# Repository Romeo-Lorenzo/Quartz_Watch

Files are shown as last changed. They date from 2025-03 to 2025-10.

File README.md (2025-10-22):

# DIY Quartz Watch project

## Introduction
This is my take at making my own quartz watch with a twist.
Driven by a PCF2003 chip from NXP as well as an STM32WB for bluetooth capability and controlling the subdial driving system in order to display data from the equipped sensors:
- Barometer
- Compass
- VBat
- Temp
- 1 cell lithium charge and discharge
- Very low power circuitry, 150nA continuous current consumption and 150mA with STM32 turned on. Designed to be equipped of two Airpods1 batteries in parralel for 50mAh total.

##Hardware:

  The hardware is divided into electrical and mecanical hardware

  ###Electrical:
  - 6 layer 36mm PCB board designed to replace original PCB from a Miyota 2035 movement. The PCB has two contact pads for two Miyota 2035 movements to drive both main and sub-dial. It is equipped with contact pads to ease programming of both the STM32 and the PCF 2003, most likely with pogo pin alignement 3D print to come.

PCB dial side
PCB caseback side
PCB
  
  - TODO Monolayer PCB to mount as shield on Nucleo board equipped with OP Amp to be able to output the voltage necessary to program the PCF 2003. Will most likely be designed as a programming station and include the pogo pins and debug connector for programming the STM32 as well and be integrated with the forementioned 3d model to print.
 
  ###Mecanical:
  - Onshape designed 36mm watch case with high water resistance in mind, a water tight push button to control subdial and STM32 ON time.
Watch assembly dial view
Watch assembly caseback view

Note that the Miyota 2035 movements will have to be modified, taking it apart and filing away the excess material on the bottom holding plate for the subdial movement is an easy fit and a tutorial on how to take apart and prepare the movements will be released.
The case is not yet finished but I estimate a 5 atm water tight watch, tolerances for CNC machinig will have to be tested. Crown will be a screw-in watertight type, a silicon membrane will ensure watertightness of the push button all the while allowing the inside barometer to read pressure, especially fun underwater.

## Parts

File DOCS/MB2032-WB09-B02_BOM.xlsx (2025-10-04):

 |  |  | Bill of materials
 |  |  | Board reference: | MB2032
 |  |  | Variant: | WB09
 |  |  | PCB revision: | B
 |  |  | Assembly revision: | 02
 |  |  | Date: | 6/21/2024
Designator | Description | Package | Manufacturer | Manufacturer_Part_Number | Fitted | Quantity
C2 | Capacitor, MLCC, 0.9pF, 50V, COG, +/-0.05pF, 0402, T=0.5mm | 0402 | MURATA | GJM1555C1HR90WB01 | Fitted | 1
C3, C6, C11, C12 | Capacitor, MLCC, 100nF, ±10%, X7R, 25V, 0402, T=0.5mm | 0402 | MURATA | GRM155R71E104KE14D | Fitted | 4
C4, C5 | Capacitor, C0G, 3 pF, 50V, NPO, ±0.1pF, 0402, T=0.5mm | 0402 | WALSIN TECHNOLOGY CORPORATION | 0402N3R0B500CT | Fitted | 2
C7 | Capacitor, MLCC, 20pF, 25V, COG, +/-2%, 0201, T=0.33mm | 0201 | MURATA | GJM0335C1E200GB01 | Fitted | 1
C8, C9 | Capacitor, MLCC, 10pF, 50V, NPO, +/-5%, 0402, T=0.5mm | 0402 | YAGEO | CC0402JRNPO9BN100 | Fitted | 2
C13 | Capacitor, MLCC, 1uF, X7R, 6.3V, 0402, ± 10%, T=0.5mm | 0402 | MURATA | GRM155R70J105KA12 | Fitted | 1
C14, C15 | Capacitor, MLCC, 4.7uF, X5R, 10 V, 0402, ± 20%, T=0.5mm | 0402 | MURATA | GRM155R61A475MEAAD | Fitted | 2
C16 | Capacitor, MLCC, 0.22uF, X5R, 6.3V, +/-10%, 0402, T=0.5mm | 0402 | YAGEO | CC0402KRX5R5BB224 | Fitted | 1
CN1, CN2 | Header, 25x2, 12.7mm, VR, SMD, T=4.83mm |  | SAMTEC | FTSH-125-02-L-DV | Fitted | 2
HW1 | RFI shield can, 20x15x3mm | 20x15x3mm | HARWIN | S02-20150300 | Fitted | 1
JP1 | Header, 3x1, 2.54mm, VR, TH, T=5.84mm/2.54mm |  | SAMTEC | TSW-103-07-F-S | Fitted | 1
L2 | Inductor, MLCC, 22nH, ±2%, 350mA, 0.58R, 0402, T=1.45mm | 0402 | MURATA | LQG15HN22NG02D | Fitted | 1
L3 | Inductor, MLCC, 10uH, ±20%, 300mA, 845mR, 0805, T=1.45mm | 0805 | MURATA | LQM21DN100M70L | Fitted | 1
R1, R10 | Resistor, 0R, 0402, +/-5%, 1/16W | 0402 | YAGEO | RC0402JR-070RL | Fitted | 2
R3 | Resistor, 100K, 0402, +/-1%, 1/16W | 0402 | YAGEO | RC0402FR-07100KL | Fitted | 1
SB6, SB7, SB9, SB11, SB14, SB16, SB17, SB20, SB28, SB32, SB34, SB37, SB38, SB41, SB43, SB47, SB48, SB55, SB57 | Solder Bridge 0402 ON | 0402 | YAGEO | RC0402JR-070RL | Fitted | 19
SC1, SC2, SC7, SC8 | shield clip Harwin S0981-46R to fix RF shielded cavity - SMT RFI Shield Clip, Corner (T+R) | 0.8x4.7x1.4mm | HARWIN | S0981-46R | Fitted | 4
SC3, SC4, SC5, SC6 | shield clip Harwin S0951-46R to fix RF shielded cavity | 1.1x3.9mm | HARWIN | S0951-46R | Fitted | 4
U1 | Bluetooth® Low Energy wireless SoC | QFN32 | STMICROELECTRONICS | STM32WB09KEV6TR | Fitted | 1
U2 | 2.4 GHz low pass filter matched to BLUENRG-LP-LPS | CSP6 | STMICROELECTRONICS | MLPF-NRG-01D3 | Fitted | 1
X1 | Crystal, 32MHz, 8pF, +/-10ppm, 60R, 2x1.6mm | 2x1.6mm | NDK | NX2016SA-32MHZ-EXS00A-CS06654 | Fitted | 1
X2 | Crystal, 32.768kHz, 7pF, +/-20ppm, 80K, 2.05x1.2mm | 2.05x1.2mm | NDK | NX2012SA-32.768KHZ-EXS00A-MU00389 | Fitted | 1
C1 | Capacitor, MLCC, 6.8pF, 50V, C0G, +/-0.05pF, 0402, T=0.5mm | 0402 | MURATA | GJM1555C1H6R8WB01 | Not Fitted | 0
C10 | Capacitor, MLCC, 100nF, ±10%, X7R, 25V, 0402, T=0.5mm | 0402 | MURATA | GRM155R71E104KE14D | Not Fitted | 0
CN3 | Header, 7x2, 1.27mm, VR, T=5.97mm, FTSH series STDC14 without Alignment Pin |  | SAMTEC | FTSH-107-01-L-DV-K | Not Fitted | 0
CN4 | Connector_RF, 0Hz to 6GHz, 50R, VR, SMD, T= 1.25mm |  | HIROSE | U.FL-R-SMT-1 | Not Fitted | 0
R2 | Resistor, 0R, 0402, +/-5%, 1/16W | 0402 | YAGEO | RC0402JR-070RL | Not Fitted | 0
R4, R5, R6, R7, R8 | Resistor, 47R, 0402, +/-1%, 1/16W | 0402 | YAGEO | RC0402FR-0747RL | Not Fitted | 0
R9 | Resistor, 100R, 0402, +/- 1%, 1/16W | 0402 | YAGEO | RC0402FR-07100RL | Not Fitted | 0
SB1, SB2, SB3, SB4, SB5, SB8, SB10, SB12, SB13, SB15, SB18, SB19, SB21, SB22, SB23, SB24, SB25, SB29, SB30, SB31, SB33, SB35, SB36, SB39, SB40, SB42, SB44, SB45, SB46, SB49, SB51, SB52, SB53, SB54, SB56 | Solder Bridge 0402 ON | 0402 | YAGEO | RC0402JR-070RL | Not Fitted | 0

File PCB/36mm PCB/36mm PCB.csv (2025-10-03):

Id | Référence | Empreinte | Quantité | Désignation | Fournisseur et réf
1 | R20,R16,R14,R15,R10,R13,R19 | R_0201_0603Metric | 7 | 100k
2 | R4,R5,R6,R12,R11,R8,R7 | R_0201_0603Metric | 7 | 2k
3 | D2 | D_0201_0603Metric | 1 | D
4 | L1 | L_0201_0603Metric | 1 | 27n
5 | R2,R1,R9 | R_0201_0603Metric | 3 | 0
6 | IC2 | BGA9C40P3X3_128X128X54 | 1 | BMM350
7 | CLPT1,C6,C7,CSPT1,C3,C2 | C_0201_0603Metric | 6 | 1u
8 | Y1 | LFXTAL062558Reel | 1 | LFXTAL062558Reel
9 | R17 | R_0201_0603Metric | 1 | 1k
10 | C4,C13,C1,C9,C17,C11,C10,C5,C16 | C_0201_0603Metric | 9 | 100n
11 | C15,C14 | C_0201_0603Metric | 2 | 4.7u
12 | C12 | C_0201_0603Metric | 1 | 220n
13 | IC3 | BGA25C40P5X5_213X207X58 | 1 | STM32L011E4Y6TR
14 | Q6,Q4,Q3,Q7,Q5 | 2N7002KQBZ | 5 | 2N7002KQBZ
15 | IC4 | TPS22991BRAAR | 1 | TPS22991BRAAR
16 | IC10,IC8,IC7,IC9 | BGA4C35P2X2_73X73X50 | 4 | MAX40200ANS+T
17 | TPS3424-1 | SOT-583-8 | 1 | ~
18 | TP15 | TestPoint_Pad_D1.0mm | 1 | B-
19 | C8 | C_0201_0603Metric | 1 | 200n
20 | IC1 | PCF2003DUS | 1 | PCF2003DUS
21 | R18 | R_0201_0603Metric | 1 | 47k
22 | U1 | BMP581 | 1 | BMP581
23 | IC6 | Hall effect | 1 | AS5510-DWLM
24 | TP14 | TestPoint_Pad_D1.0mm | 1 | B+
25 | IC5 | SON50P300X200X100-9N-D | 1 | MCP73831-2ACI_MC
26 | J3 | Battery pogo pins | 1 | Conn_01x02
27 | LDLN025PU1 | OnSemi_XDFN4-1EP_1.0x1.0mm_EP0.52x0.52mm | 1 | ~
28 | TP18 | Pogo pin 1x1 | 1 | SWCLK
29 | L3,L2 | Miyota 2035 | 2 | L
30 | TP21 | Pogo pin 1x1 | 1 | VSS
31 | SW5 | Wurth side button 434331013822 | 1 | SW_MEC_5E
32 | TP20 | Pogo pin 1x1 | 1 | VDD
33 | TP19 | Pogo pin 1x1 | 1 | NRST
34 | TP16 | Pogo pin 1x1 | 1 | VDD Prog
35 | TP17 | Pogo pin 1x1 | 1 | SWDIO

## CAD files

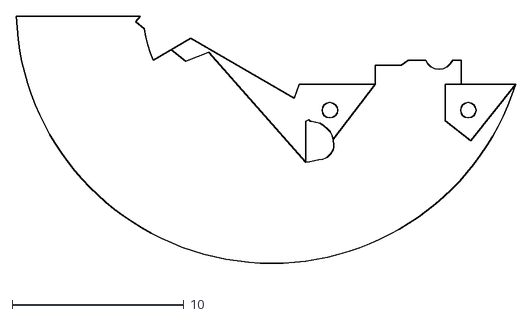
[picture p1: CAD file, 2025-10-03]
PCB/36mm PCB/36mm PCB outline.dxf
29.1 x 15.2

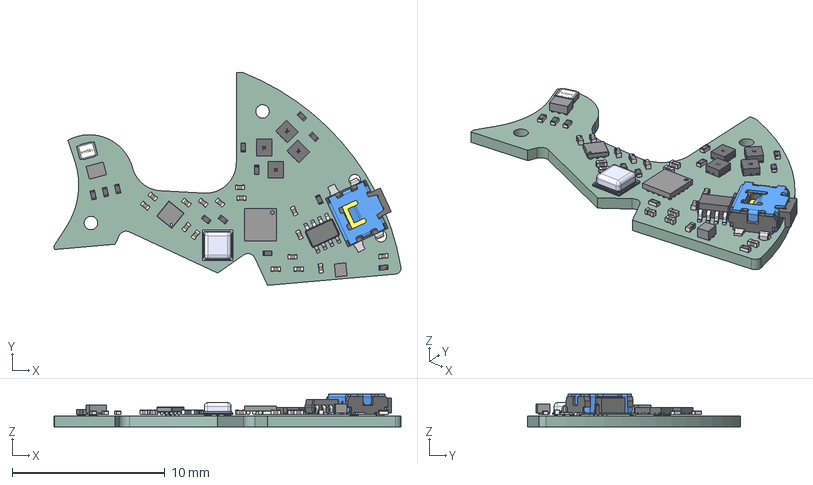
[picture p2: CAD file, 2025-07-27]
PCB/Watch_PCB/Watch_PCB.step
22.7 x 13.9 x 2.14 mm
C_0201_0603Metric x 15
ABS04W-32.768KHZ-4-D2-T5
R_0201_0603Metric x 12
Pins x 2
SOT8015 LF x 4
SOT8015 Body x 4
L_0201_0603Metric
Frame
washer
Contact plate
Stem
Cover
BMP581
BMM350
SC-70-8
Watch_PCB_PCB

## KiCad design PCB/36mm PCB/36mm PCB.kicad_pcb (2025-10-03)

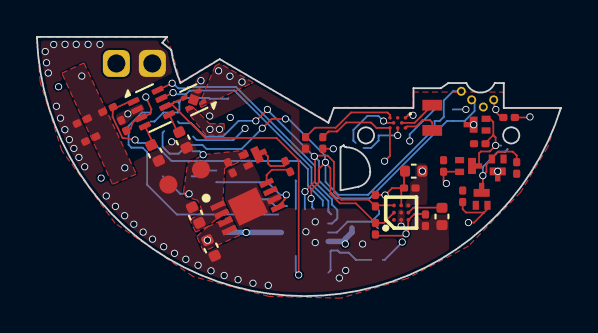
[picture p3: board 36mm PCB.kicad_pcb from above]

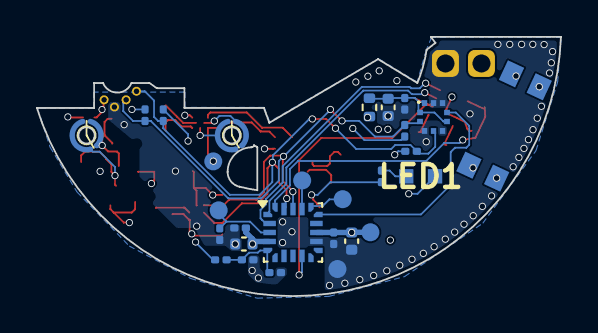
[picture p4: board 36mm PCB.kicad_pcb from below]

Board: 6 copper layers, 29.1 x 14.4 mm, 65 parts (28 on the bottom side), 34 nets.

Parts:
C9, C10, C11, C17, C21, C24, C27, C28, C29: 100n; C_0201_0603Metric
C15, C22: 4.7u; C_0402_1005Metric
C18: 2.2u; C_0402_1005Metric
C20: 220n; C_0201_0603Metric
C23, C25, C26, C30: 1u; C_0402_1005Metric
CLPT1: 11.8n; C_0402_1005Metric
CSPT1: 4.7n; C_0402_1005Metric
IC1: PCF2003DUS
IC2: BMM350; BGA9C40P3X3_128X128X54
IC5: MCP73831-2ACI_MC; SON50P300X200X100-9N-D
J1: Conn_01x04_Pin; Hall effect
J2: Conn_01x02_Socket; Battery 36mm watch
J3: Conn_01x02; Battery pogo pins
L2, L3: L; Miyota 2035
LDLN025PU1: OnSemi_XDFN4-1EP_1.0x1.0mm_EP0.52x0.52mm
LED1: 150060WS75000
Q3, Q4, Q5, Q6, Q7: 2N7002KQBZ
R1, R2: 0; R_0201_0603Metric
R3, R4, R5, R9, R22, R23: 4.7k; R_0201_0603Metric
R6: 500; R_0201_0603Metric
R7, R8, R13, R14, R18, R19, R20: 100k; R_0201_0603Metric
R11: 10; R_0402_1005Metric
R15: 47k; R_0201_0603Metric
R16: 1k; R_0201_0603Metric
R17: 2k; R_0201_0603Metric
SW5: SW_MEC_5E; Wurth side button 434331013822
TP16: VDD Prog; Pogo pin 1x1
TP17: SWDIO; Pogo pin 1x1
TP18: SWCLK; Pogo pin 1x1
TP19: NRST; Pogo pin 1x1
TP20: 3.3V; Pogo pin 1x1
TP21: VSS; Pogo pin 1x1
TPS3424A11C13ADRLR1: SOT-583-8
U1: BMP581
U2: STM32L011F4Ux; ST_UFQFPN-20_3x3mm_P0.5mm
Y1: LFXTAL062558Reel

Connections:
+3.3V: C9.2, C11.2, C17.2, C23.1, C24.2, C26.1, C29.2, C30.1, IC2.B3 (VDDIO), IC2.C1 (VDD), J1.1, LDLN025PU1.1 (Vout), Q3.2 (S), Q4.2 (S), R3.1, R4.1, R5.2, R7.1, R9.1, R11.1, R14.1, R22.2, R23.2, TP20.1, U2.4 (VDDA), U2.13 (VDD)
+3V0: C15.1, C21.2, IC5.3 (VBAT_1), IC5.4 (VBAT_2), J2.1, LDLN025PU1.4 (Vin_), R1.2, R16.1, R19.1, TPS3424A11C13ADRLR1.3 (VDD)
/BMP581_INT: U1.7 (INT), U2.15 (PA10)
/Button press: R15.2, TPS3424A11C13ADRLR1.1 (PB), U2.20 (PB9)
/H_Tim1: Q3.1 (G), Q6.1 (G), R7.2, R13.2, U2.6 (PA1)
/H_Tim2: Q4.1 (G), Q5.1 (G), R8.2, R14.2, U2.8 (PA5)
/I2C_SCL: IC2.A3 (SCK), J1.3, R4.2, R5.1, R23.1, U1.2 (SCK), U2.18 (PB6)
/I2C_SDA: IC2.A2 (SDA), J1.4, R3.2, R9.2, R22.1, U1.4 (SDI), U2.19 (PB7)
/KeepOn: LDLN025PU1.3 (EN), TPS3424A11C13ADRLR1.6 (RESET/~RESET~), U2.9 (PA6)
/Kill: TPS3424A11C13ADRLR1.8 (kill), U2.2 (PC15)
/L-S press INT: TPS3424A11C13ADRLR1.7 (~INT~), U2.1 (PC14)
/Main dial/OSCIN: IC1.B2 (OSCIN), Y1.2 (CRYSTAL_2)
/Main dial/OSCOUT: IC1.C1 (OSCOUT), Y1.1
/Main dial/VDD PROG: IC1.C5 (VDD), R1.1, TP16.1
/NRST: C27.2, TP19.1, U2.3 (NRST)
/Peripherals/VDDIO: C10.2, C25.1, R11.2, U1.1 (VDDIO), U1.6 (CSB), U1.10 (VDD)
/Power/Charge +: C22.1, IC5.1 (VDD_1), IC5.2 (VDD_2), J3.2, LED1.1 (A), Q7.1 (G), R18.1
/Power/STAT: IC5.5 (STAT), R6.1
/SWCLK: TP18.1, U2.17 (PA14)
/SWDIO: TP17.1, U2.16 (PA13)
GND: C9.1, C10.1, C11.1, C15.2, C17.1, C18.2, C20.1, C21.1, C22.2, C23.2, C24.1, C25.2, C26.2, C27.1, C28.1, C29.1, C30.2, CLPT1.1, CSPT1.1, IC1.A1 (VSS), IC2.B1 (GND), IC2.B2 (ADSEL), IC2.C3 (BYPASS), IC5.6 (VSS), IC5.9 (EP), J1.2, J2.2, J3.1, LDLN025PU1.2 (GND), LDLN025PU1.5 (GND), Q5.3 (D_1), Q5.4 (D_2), Q6.3 (D_1), Q6.4 (D_2), Q7.2 (S), R2.1, R18.2, R20.1, SW5.1, SW5.3, TP21.1, TPS3424A11C13ADRLR1.2 (GND), U1.3 (VSS_1), U1.5 (SDO), U1.8 (VSS_2), U1.9 (VSS_3), U2.12 (VSS)
unnamed: C20.2, R15.1, R16.2, SW5.2, SW5.4
unnamed: IC1.C3 (MOT1), L3.2
unnamed: IC1.B4 (MOT2), L3.1
unnamed: IC1.A5 (RESET), R2.2
unnamed: C18.1, IC2.C2 (CRST)
unnamed: IC5.8 (PROG), R17.2
unnamed: LED1.2 (K), R6.2
unnamed: L2.1, Q3.3 (D_1), Q3.4 (D_2), Q5.2 (S), R8.1
unnamed: L2.2, Q4.3 (D_1), Q4.4 (D_2), Q6.2 (S), R13.1
unnamed: Q7.3 (D_1), Q7.4 (D_2), R17.1
unnamed: CLPT1.2, TPS3424A11C13ADRLR1.5 (LPT)
unnamed: CSPT1.2, TPS3424A11C13ADRLR1.4 (SPT)
unnamed: C28.2, R19.2, R20.2, U2.5 (PA0)

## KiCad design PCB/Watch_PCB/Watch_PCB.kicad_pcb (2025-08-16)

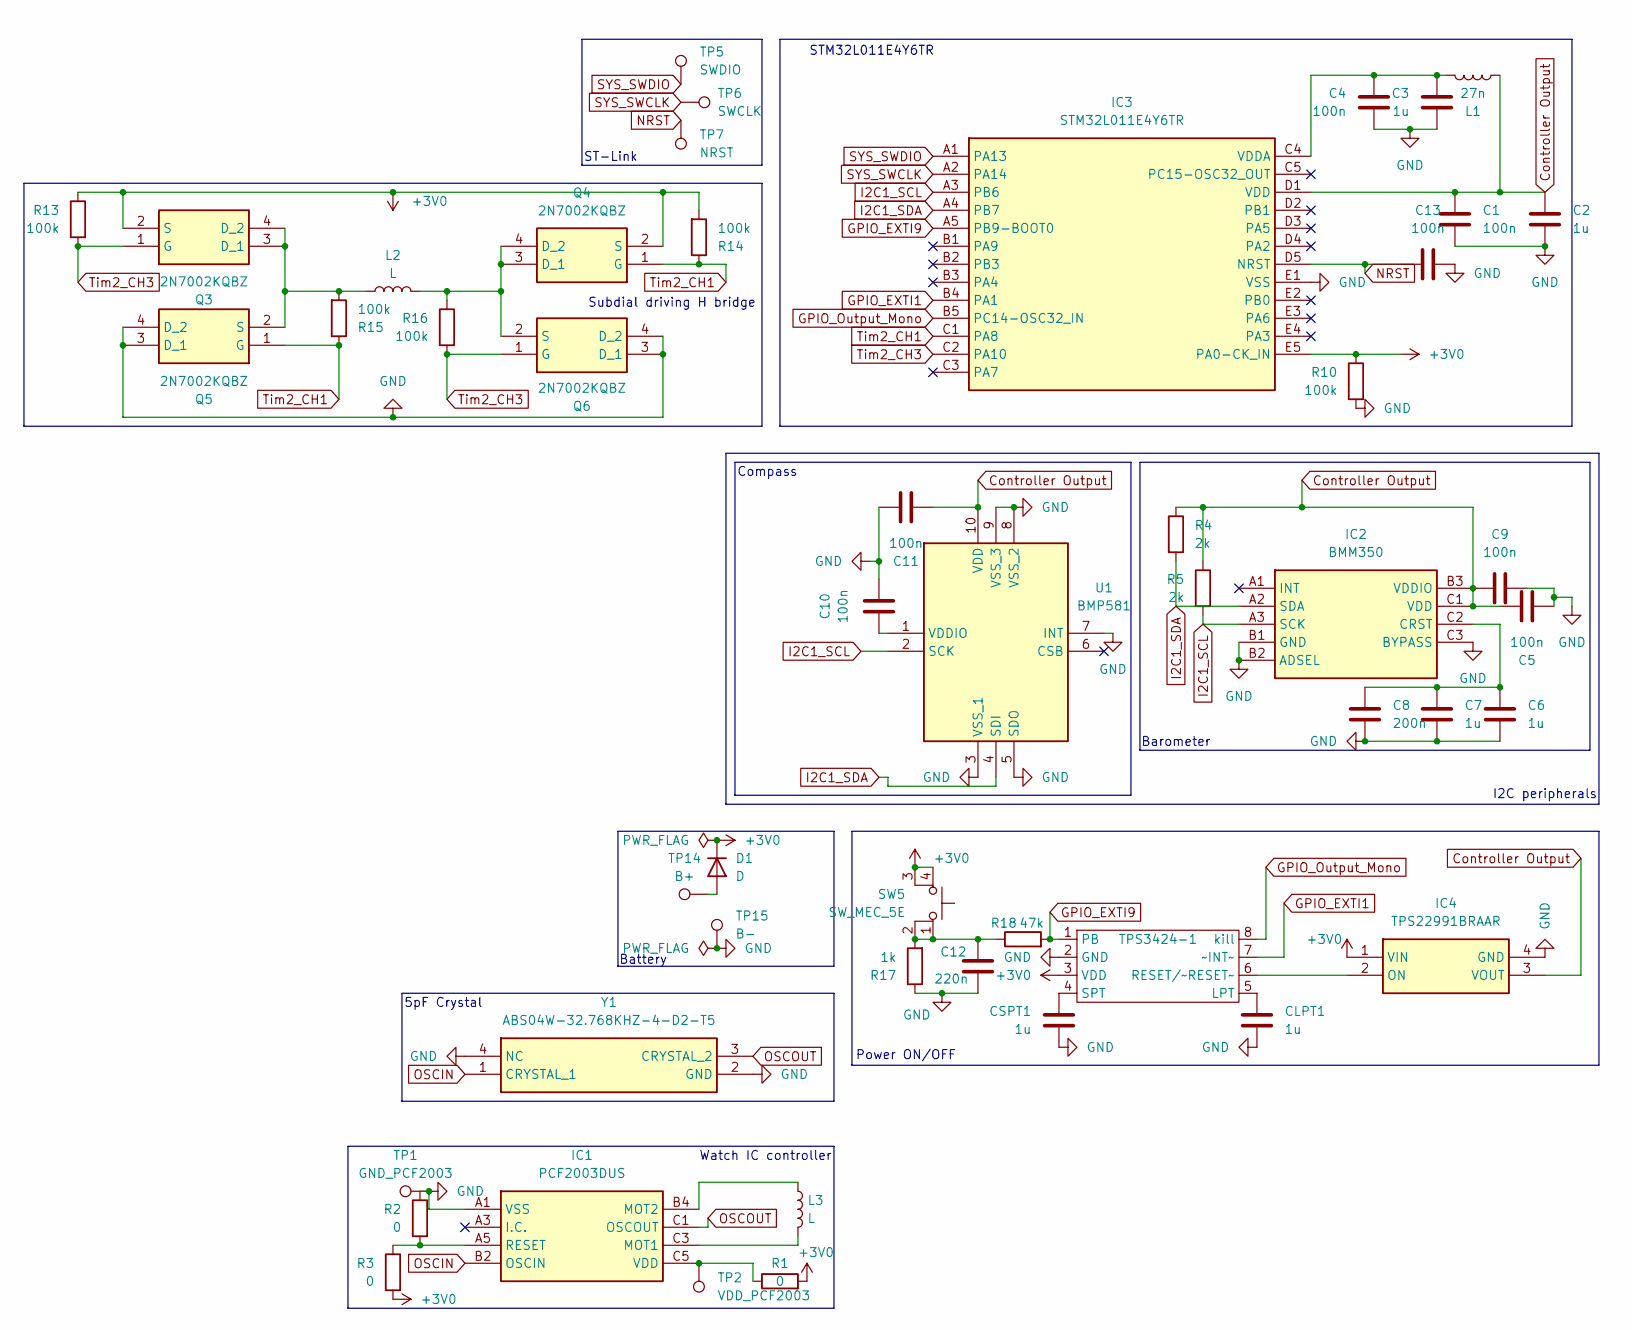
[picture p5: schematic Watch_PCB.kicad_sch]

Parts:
C1, C4, C5, C9, C10, C11, C13: 100n; C_0201_0603Metric
C2, C3, C6, C7: 1u; C_0201_0603Metric
C8: 200n; C_0201_0603Metric
C12: 220n; C_0201_0603Metric
CLPT1: 1u; C_0201_0603Metric
CSPT1: 1u; C_0201_0603Metric
D1: D; D_0201_0603Metric
IC1: PCF2003DUS; Manufacturer_Part_Number PCF2003DUS
IC2: BMM350; BGA9C40P3X3_128X128X54; Mouser Part Number 262-BMM350
IC3: STM32L011E4Y6TR; BGA25C40P5X5_213X207X58; Manufacturer_Part_Number STM32L011E4Y6TR; Mouser Part Number 511-STM32L011E4Y6TR
IC4: TPS22991BRAAR; Manufacturer_Part_Number TPS22991BRAAR; Mouser Part Number 595-TPS22991BRAAR
L1: 27n; L_0201_0603Metric
L2, L3: L; Miyota 2035
Q3, Q4, Q5, Q6: 2N7002KQBZ; Manufacturer_Part_Number 2N7002KQBZ; Mouser Part Number 771-2N7002KQBZ
R1, R2, R3: 0; R_0201_0603Metric
R4, R5: 2k; R_0201_0603Metric
R10, R13, R14, R15, R16: 100k; R_0201_0603Metric
R17: 1k; R_0201_0603Metric
R18: 47k; R_0201_0603Metric
SW5: SW_MEC_5E; Wurth side button 434331013822
TP1: GND_PCF2003; TestPoint_Pad_D1.0mm
TP2: VDD_PCF2003; TestPoint_Pad_D1.0mm
TP5: SWDIO; TestPoint_Pad_D1.0mm
TP6: SWCLK; TestPoint_Pad_D1.0mm
TP7: NRST; TestPoint_Pad_D1.0mm
TP14: B+; TestPoint_Pad_D1.0mm
TP15: B-; TestPoint_Pad_D1.0mm
TPS3424-1: SOT-583-8
U1: BMP581; Manufacturer_Part_Number BMP581; Mouser Part Number 262-BMP581
Y1: ABS04W-32.768KHZ-4-D2-T5; ABS04W32768KHZ4D2T5; Manufacturer_Part_Number ABS04W-32.768KHZ-4-D2-T5; Mouser Part Number 815-04W-32.768-4-D2T

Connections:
+3V0: D1.1 (K), IC3.E5 (PA0-CK_IN), IC4.1 (VIN), Q3.2 (S), Q4.2 (S), R1.2, R3.2, R10.1, R13.1, R14.2, SW5.3 (K), SW5.4 (A), TPS3424-1.3 (VDD)
Controller Output: C1.2, C2.2, C5.1, C9.1, C11.2, IC2.B3 (VDDIO), IC2.C1 (VDD), IC3.D1 (VDD), IC4.3 (VOUT), L1.1, R4.1, R5.1, U1.10 (VDD)
GND: C1.1, C2.1, C3.1, C4.1, C5.2, C6.2, C7.2, C8.2, C9.2, C10.1, C11.1, C12.1, C13.2, CLPT1.1, CSPT1.1, IC1.A1 (VSS), IC2.B1 (GND), IC2.B2 (ADSEL), IC2.C3 (BYPASS), IC3.E1 (VSS), IC4.4 (GND), Q5.3 (D_1), Q5.4 (D_2), Q6.3 (D_1), Q6.4 (D_2), R2.1, R10.2, R17.1, TP1.1, TP15.1, TPS3424-1.2 (GND), U1.3 (VSS_1), U1.5 (SDO), U1.7 (INT), U1.8 (VSS_2), U1.9 (VSS_3), Y1.2 (GND), Y1.4 (NC)
GPIO_EXTI1: IC3.B4 (PA1), TPS3424-1.7 (~INT~)
GPIO_EXTI9: IC3.A5 (PB9-BOOT0), R18.2, TPS3424-1.1 (PB)
GPIO_Output_Mono: IC3.B5 (PC14-OSC32_IN), TPS3424-1.8 (kill)
I2C1_SCL: IC2.A3 (SCK), IC3.A3 (PB6), R5.2, U1.2 (SCK)
I2C1_SDA: IC2.A2 (SDA), IC3.A4 (PB7), R4.2, U1.4 (SDI)
NRST: C13.1, IC3.D5 (NRST), TP7.1
unnamed: C12.2, R17.2, R18.1, SW5.1, SW5.2
unnamed: D1.2 (A), TP14.1
unnamed: IC1.C3 (MOT1), L3.2
unnamed: IC1.B4 (MOT2), L3.1
unnamed: IC1.A5 (RESET), R2.2, R3.1
unnamed: IC1.C5 (VDD), R1.1, TP2.1
unnamed: C6.1, C7.1, C8.1, IC2.C2 (CRST)
unnamed: C3.2, C4.2, IC3.C4 (VDDA), L1.2
unnamed: IC4.2 (ON), TPS3424-1.6 (RESET/~RESET~)
unnamed: L2.1, Q3.3 (D_1), Q3.4 (D_2), Q5.2 (S), R15.2
unnamed: L2.2, Q4.3 (D_1), Q4.4 (D_2), Q6.2 (S), R16.1
unnamed: CLPT1.2, TPS3424-1.5 (LPT)
unnamed: CSPT1.2, TPS3424-1.4 (SPT)
unnamed: C10.2, U1.1 (VDDIO)
OSCIN: IC1.B2 (OSCIN), Y1.1 (CRYSTAL_1)
OSCOUT: IC1.C1 (OSCOUT), Y1.3 (CRYSTAL_2)
SYS_SWCLK: IC3.A2 (PA14), TP6.1
SYS_SWDIO: IC3.A1 (PA13), TP5.1
Tim2_CH1: IC3.C1 (PA8), Q4.1 (G), Q5.1 (G), R14.1, R15.1
Tim2_CH3: IC3.C2 (PA10), Q3.1 (G), Q6.1 (G), R13.2, R16.2

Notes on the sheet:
5pF Crystal
ST-Link
Power ON/OFF
Subdial driving H bridge
Compass
Watch IC controller
I2C peripherals
Barometer
Battery
STM32L011E4Y6TR

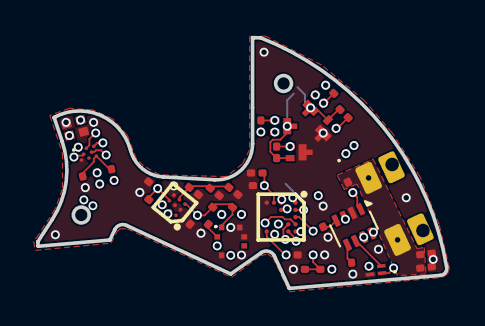
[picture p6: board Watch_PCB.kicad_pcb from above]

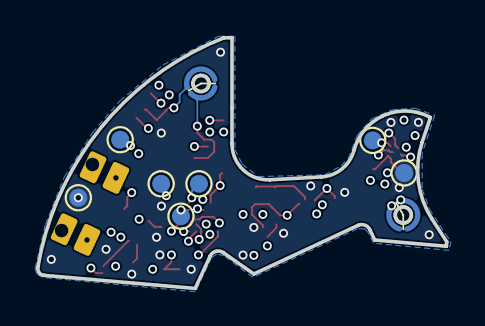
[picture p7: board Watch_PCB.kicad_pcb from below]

Board: 6 copper layers, 22.7 x 13.9 mm, 50 parts (9 on the bottom side), 29 nets.

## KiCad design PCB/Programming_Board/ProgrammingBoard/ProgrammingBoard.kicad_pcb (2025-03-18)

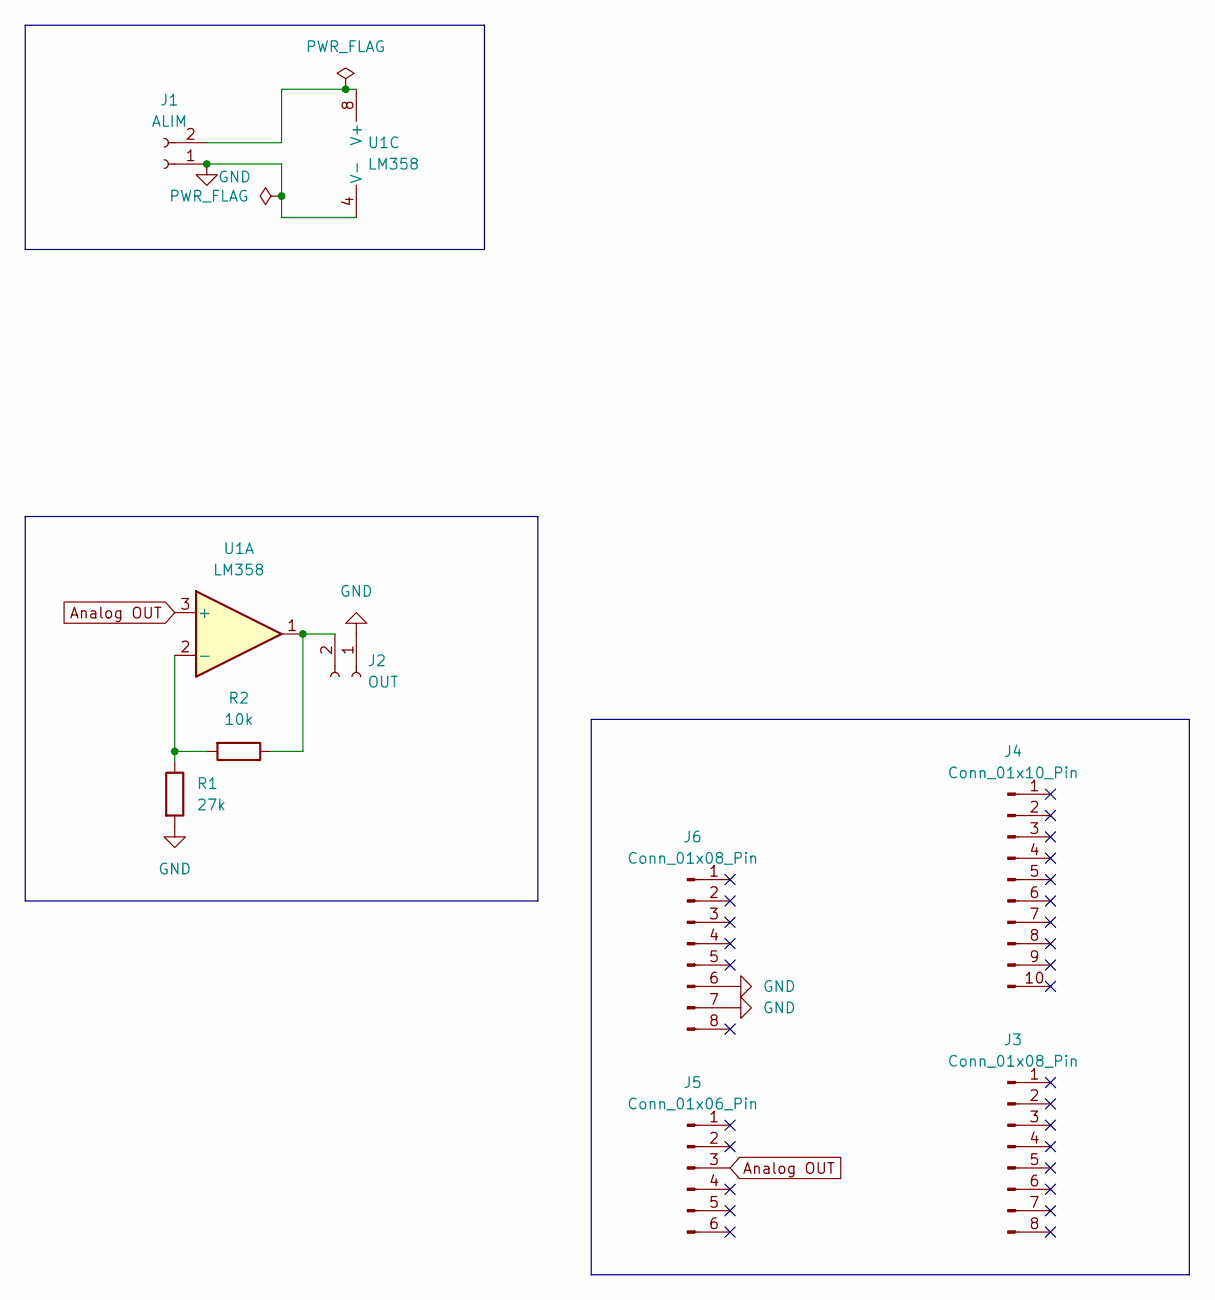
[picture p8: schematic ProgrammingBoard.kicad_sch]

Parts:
J1: ALIM; PinSocket_1x02_P2.54mm_Vertical
J2: OUT; PinSocket_1x02_P2.54mm_Vertical
J3, J6: Conn_01x08_Pin; PinHeader_1x08_P2.54mm_Vertical
J4: Conn_01x10_Pin; PinHeader_1x10_P2.54mm_Vertical
J5: Conn_01x06_Pin; PinHeader_1x06_P2.54mm_Vertical
R1: 27k; R_Axial_DIN0204_L3.6mm_D1.6mm_P5.08mm_Horizontal
R2: 10k; R_Axial_DIN0204_L3.6mm_D1.6mm_P5.08mm_Horizontal
U1: LM358; LM358P

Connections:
Analog OUT: J5.3, U1.3 (+)
GND: J1.1, J2.1, J6.6, J6.7, R1.2, U1.4 (V-)
unnamed: J1.2, U1.8 (V+)
unnamed: J2.2, R2.1, U1.1
unnamed: R1.1, R2.2, U1.2 (-)

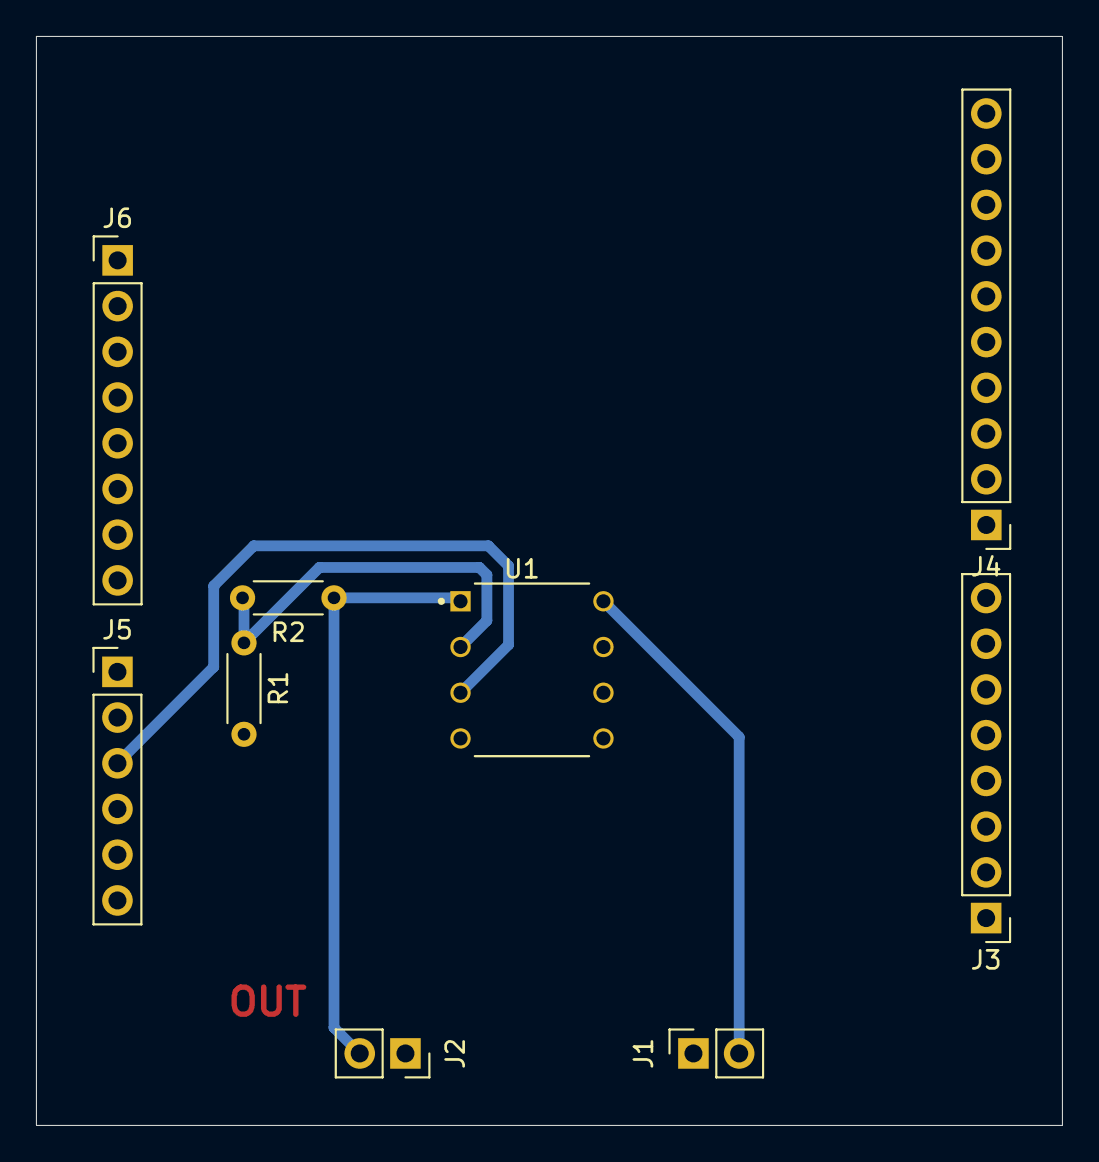
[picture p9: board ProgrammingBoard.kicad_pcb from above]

Board: 2 copper layers, 57.0 x 60.5 mm, 9 parts (0 on the bottom side), 5 nets.

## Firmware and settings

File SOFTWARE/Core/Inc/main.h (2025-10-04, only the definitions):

#define Kill_Pin GPIO_PIN_3
#define Kill_GPIO_Port GPIOB
#define KeepOn_Pin GPIO_PIN_2
#define KeepOn_GPIO_Port GPIOB
#define Button_Pin GPIO_PIN_1
#define Button_GPIO_Port GPIOB
#define EXTI_Baro_Pin GPIO_PIN_8
#define EXTI_Baro_GPIO_Port GPIOA
#define H_on_GPIO_Pin GPIO_PIN_14
#define H_on_GPIO_GPIO_Port GPIOB
#define PCF2003_Reset_Pin GPIO_PIN_5
#define PCF2003_Reset_GPIO_Port GPIOB
#define EXTI_LS_Press_Pin GPIO_PIN_4
#define EXTI_LS_Press_GPIO_Port GPIOB

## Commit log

2025-03-18 Programming board
    [IC_ProgrammingBoard.kicad_pcb, IC_ProgrammingBoard.kicad_sch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]
2025-06-22 Watch PCB schema
    Watch PCB schematictic
    [Watch_PCB.kicad_pcb, Watch_PCB.kicad_sch]
2025-06-22 added debounce on switch
    [Watch_PCB.kicad_sch]
2025-06-22 pcb outline
    [Watch_PCB.kicad_pcb, Watch_PCB.kicad_sch]
2025-06-30 pcb layout
    pcb layout
    [Watch_PCB.kicad_pcb, Watch_PCB.kicad_sch]
2025-07-27 PCB V1
    PCB V1 complete
    [Watch_PCB.kicad_pcb, Watch_PCB.kicad_sch, Watch_PCB.step]
2025-08-16 36mm pcb
    [36mm PCB outline.dxf, 36mm PCB.kicad_pcb, 36mm PCB.kicad_sch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]
2025-10-03 PCB 2.0
    [36mm PCB outline.dxf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]
2025-10-03 Safety push
    [36mm PCB.kicad_pcb]
2025-10-03 Modifs Mathieu
    [36mm PCB.kicad_sch, MainDial.kicad_sch, Power.kicad_sch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]
2025-10-04 STM32 BLE + H chip
    [36mm PCB.kicad_pcb, 36mm PCB.kicad_sch, Power.kicad_sch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]

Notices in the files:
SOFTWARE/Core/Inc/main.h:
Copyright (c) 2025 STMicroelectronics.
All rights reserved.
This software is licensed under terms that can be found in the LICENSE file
